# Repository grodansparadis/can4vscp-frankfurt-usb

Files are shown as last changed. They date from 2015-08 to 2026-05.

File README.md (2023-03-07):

<h1>Frankfurt USB</h1>



Buffered and isolated interface for CAN4VSCP

Frankurt USB is a high speed USB interface to the CAN4VSCP bus. It is not available inte 
<a href="http://www.frogshop.se">FrogShop</a> at the moment but will probaly be available this year.

It is planed in two versions. One for DIN montage/wall mountage as the rest of the CAN4VSCP modules and
one version that is boxed.
<hr>

This project is part of the <a href="http://www.vscp.org">VSCP (Very Simple Control Protocol) project</a>. 

<hr>

This project is licensed under the 
<a href="http://creativecommons.org/licenses/by-nc-sa/3.0/">Creative Commons open source license Attribution-NonCommercial-ShareAlike 3.0 Unported</a>. 
Other license options are available by conacting <a href="malto:info@grodansparadis.com">Paradis of the Frog AB</a>

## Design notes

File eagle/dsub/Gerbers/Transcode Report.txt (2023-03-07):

   ---- Transcoding 'C:\Users\grodansparadis\development\can4vscp_frankfurt_usb\eagle\dsub\Gerbers\pactec_version_rev_C.milling' ----   Mon Nov 02 14:24:04 2015

D10   --> D100
-----------------------------------------------------------------

   ---- Transcoding 'C:\Users\grodansparadis\development\can4vscp_frankfurt_usb\eagle\dsub\Gerbers\pactec_version_rev_C.plc' ----   Mon Nov 02 14:24:04 2015

D10   --> D103
D11   --> D104
D12   --> D105
D13   --> D106
D14   --> D107
D15   --> D108
D16   --> D109
D17   --> D110
D18   --> D111
D19   --> D112
D20   --> D113
D21   --> D114
D22   --> D115
D23   --> D116
D24   --> D117
D25   --> D118
D26   --> D119
D27   --> D120
D28   --> D121
D29   --> D122
D30   --> D123
D31   --> D124
D32   --> D125
D100  --> D126
-----------------------------------------------------------------

   ---- Transcoding 'C:\Users\grodansparadis\development\can4vscp_frankfurt_usb\eagle\dsub\Gerbers\pactec_version_rev_C.pls' ----   Mon Nov 02 14:24:04 2015

D10   --> D127
D11   --> D128
-----------------------------------------------------------------

   ---- Transcoding 'C:\Users\grodansparadis\development\can4vscp_frankfurt_usb\eagle\dsub\Gerbers\pactec_version_rev_C.pmc' ----   Mon Nov 02 14:24:04 2015

D10   --> D129
D11   --> D130
D12   --> D131
D13   --> D132
D14   --> D133
D15   --> D134
D16   --> D135
D17   --> D136
D18   --> D137
D19   --> D138
D20   --> D139
D21   --> D140
-----------------------------------------------------------------

   ---- Transcoding 'C:\Users\grodansparadis\development\can4vscp_frankfurt_usb\eagle\dsub\Gerbers\pactec_version_rev_C.pms' ----   Mon Nov 02 14:24:04 2015

D10   --> D141
-----------------------------------------------------------------

   ---- Transcoding 'C:\Users\grodansparadis\development\can4vscp_frankfurt_usb\eagle\dsub\Gerbers\pactec_version_rev_C.sol' ----   Mon Nov 02 14:24:04 2015

D13   --> D142
D14   --> D143
D15   --> D144
D16   --> D145
D17   --> D146
D18   --> D147
D19   --> D148
D20   --> D149
D21   --> D150
-----------------------------------------------------------------

   ---- Transcoding 'C:\Users\grodansparadis\development\can4vscp_frankfurt_usb\eagle\dsub\Gerbers\pactec_version_rev_C.stc' ----   Mon Nov 02 14:24:04 2015

D10   --> D151
D11   --> D152
D12   --> D153
D13   --> D154
D14   --> D155
D15   --> D156
D16   --> D157
D17   --> D158
D18   --> D159
D19   --> D160
D20   --> D161
D21   --> D162
D22   --> D163
D23   --> D164
D24   --> D165
D25   --> D166
D26   --> D167
D27   --> D168
D28   --> D169
-----------------------------------------------------------------

   ---- Transcoding 'C:\Users\grodansparadis\development\can4vscp_frankfurt_usb\eagle\dsub\Gerbers\pactec_version_rev_C.sts' ----   Mon Nov 02 14:24:04 2015

D10   --> D170
D11   --> D171
D12   --> D172
D13   --> D173
D14   --> D174
D15   --> D175
D16   --> D176
D17   --> D177
-----------------------------------------------------------------

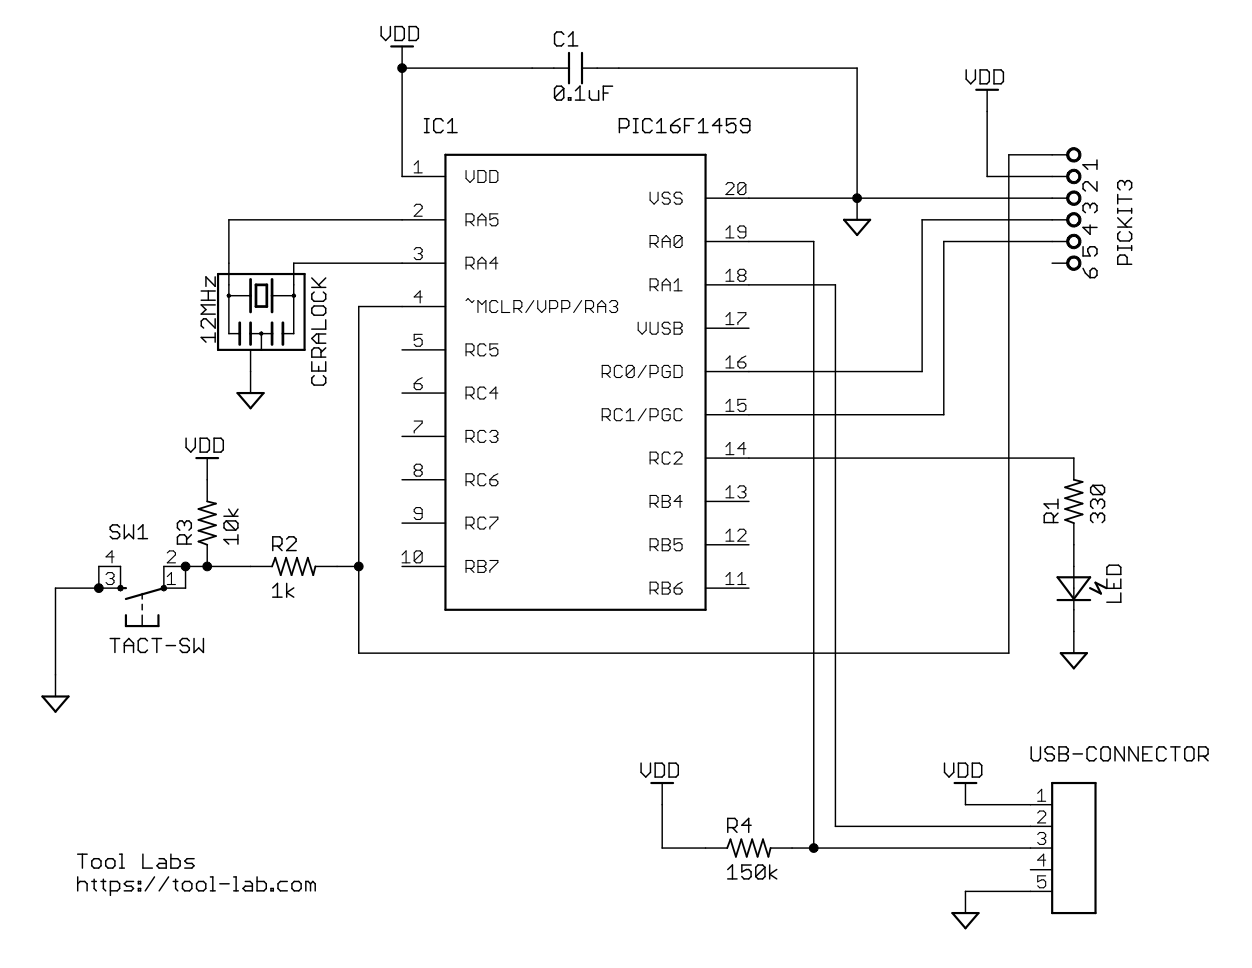
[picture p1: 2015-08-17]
docs/schematics-16F1459.png

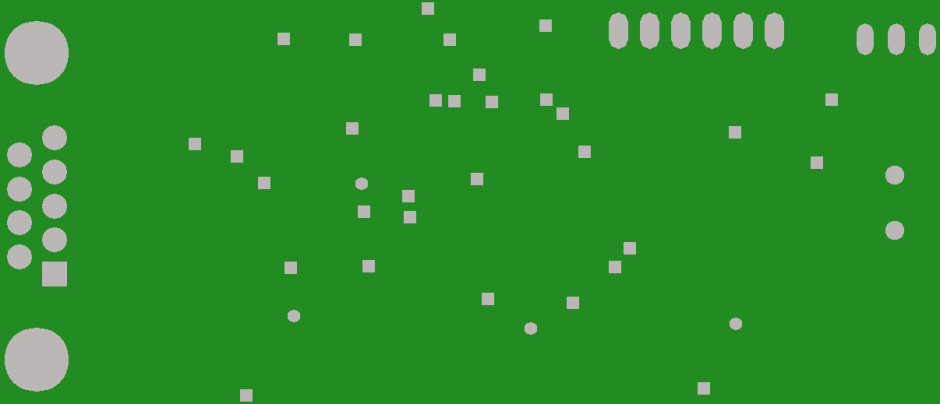
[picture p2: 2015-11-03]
eagle/dsub/Gerbers/frankfurt_usb_pac_rev_c_gbs_small.png

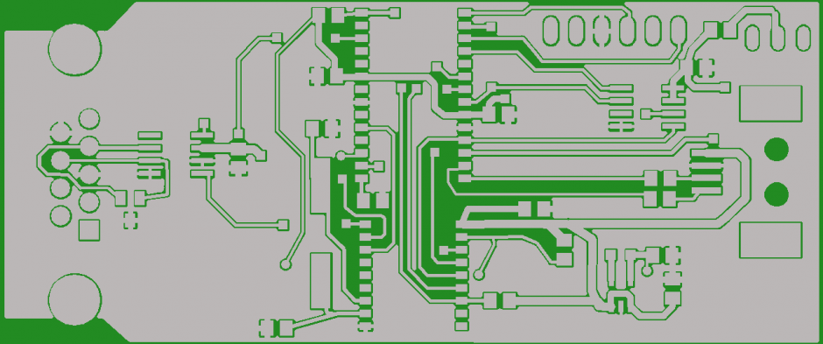
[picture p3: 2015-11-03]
eagle/dsub/Gerbers/frankfurt_usb_pac_rev_c_gtl_small.png

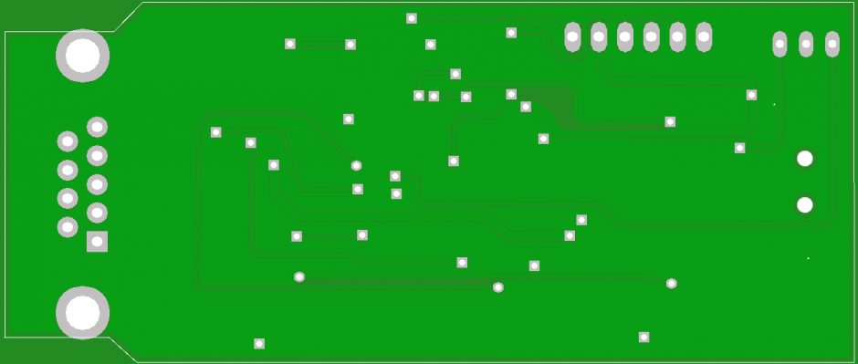
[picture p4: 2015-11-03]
eagle/dsub/Gerbers/frankfurt_usb_pac_rev_c_bottom_small.png

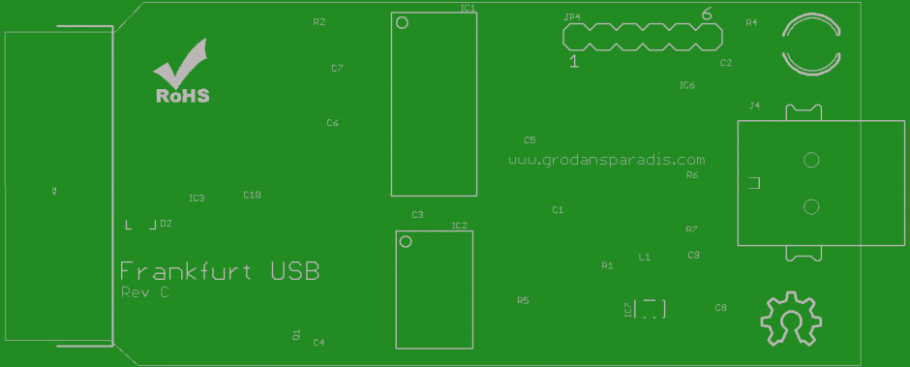
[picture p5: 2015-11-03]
eagle/dsub/Gerbers/frankfurt_usb_pac_rev_c_gto_small.png

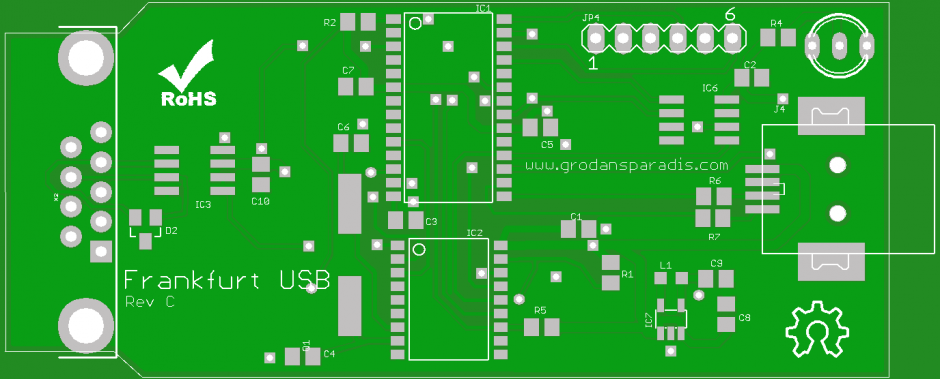
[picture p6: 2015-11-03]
eagle/dsub/Gerbers/frankfurt_usb_pac_rev_c_top_small.png

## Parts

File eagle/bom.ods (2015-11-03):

Partl | ist exported from | C:/Users/akhe/Doc | uments/develo | pment/hardware_zeus/can4vscp/can4vscp_usb/eagle/smd_can | 4vscp_usb_0.0.2.sch at 2 | 011-10-03 | 11:29:21
Part | Value | Device | Package | Description | Description | Supplier | Partnumber | Price
C1 | 100nF | C-EUC0805 | C0805 | CAPACITOR, European symbol | Avkopplingskondensator | Bejoken | 522526 | 0,07
C2 | 0.1uF | C-EUC0805 | C0805 | CAPACITOR, European symbol | Avstörningskondensator | Bejoken | 522526 | 0,07
C4 | 15pF | C-EUC0805 | C0805 | CAPACITOR, European symbol | Kondensator | Bejoken | 522419 | 0,11
C5 | 0.1uF | C-EUC0805 | C0805 | CAPACITOR, European symbol | Avstörningskondensator | Bejoken | 522526 | 0,07
C6 | 15pF | C-EUC0805 | C0805 | CAPACITOR, European symbol | Kondensator | Bejoken | 522419 | 0,11
D2 | NUP2105L | DIODE-2CA|ACSOT23 | SOT23 | Dual DIODE Cathode-Anode|Anode-Cathode | Tansient protection | Digikey | NUP2105LT1GOSCT-ND | 4
IC1 | PIC18LF2550-I/SO | PIC18LF2550-I/SO | SO-28W | PIC18*2550 Microchip FLASH Microcontroller with FS-USB | USB Microcontrole | Digikey | PIC18F2550-I/SO-ND | 50,4
IC2 | MCP2515 | MCP2515 | SO-18W |  | CAN Controller | Digikey | MCP2515-I/SO-ND | 15,84
IC3 | MCP2551SN | MCP2551SN | SO-08 | High Speed CAN tranceiver | CAN tranceiver | Digikey | MCP2551-I/SN-ND | 8,96
IC4 | ISO1050 | ISO1050 | DUB_PSOP |  | Isolated CAN tranceiver | Digikey | 296-24818-1-ND | 37,2
IC5 | DCDC_MER1 | DCDC_MER1 | MER1 |  | DC DC converter | Digikey | 811-2124-5-ND | 63,6
IC6 | MCP23A256 | MCP23A256 | SO-8 |  | Serial RAM | Digikey | 23A256-I/SN-ND | 12,96
J2 | A00-108-220-450 | A00-108-220-450 | RJ-45 |  | RJ-45 connector | Digikey | 151-1099-nd | 5,6
J3 |  | MA03-1 | MA03-1 | PIN HEADER | Enkel stiftlist | Digikey | SAM1035-50-ND | 0,33
JP4 |  | MA06-1 | MA06-1 | PIN HEADER | Enkel stiftlist | Digikey | SAM1035-50-ND | 0,33
LED1 |  | LEDCHIP-LED0805 | CHIP-LED0805 | LED | Green LED | Digikey | 475-1410-1-nd | 0,88
LED2 |  | LEDCHIP-LED0805 | CHIP-LED0805 | LED | Green LED | Digikey | 475-1410-1-nd | 0,88
Q1 | 12 MHZ | HC-49S | 9C | Digikey 887-1050-1-nd | Crystal | Digikey | 887-1053-1-ND | 2,56
R1 | 10K | R-EU_R0805 | R0805 | RESISTOR, European symbol | Resistor | Bejoken | 454676 | 0,01
R2 | 10K | R-EU_R0805 | R0805 | RESISTOR, European symbol | Resistor | Bejoken | 454676 | 0,01
R3 | 1K | R-EU_R0805 | R0805 | RESISTOR, European symbol | Resistor | Bejoken | 454650 | 0,01
R4 | 1K | R-EU_R0805 | R0805 | RESISTOR, European symbol | Resistor | Bejoken | 454650 | 0,01
R5 | 10K | R-EU_R0805 | R0805 | RESISTOR, European symbol | Resistor | Bejoken | 454676 | 0,01
X1 | USB-B-S | USB-B-S | USB-B-SMT | USB Connectors | USB B connector | Digikey | ED2994-ND | 8,8
 |  |  |  |  |  |  |  | 212,82

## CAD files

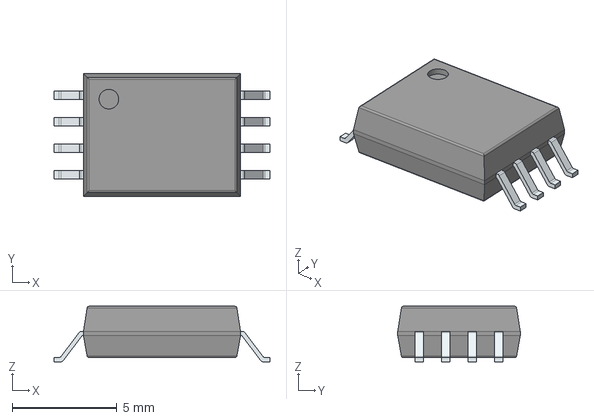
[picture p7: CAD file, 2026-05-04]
kicad/lbr/ADM3050EBRIZ-RL/3D/ADM3050EBRIZ-RL.stp
10.3 x 5.85 x 2.65 mm
PinsArrayLR

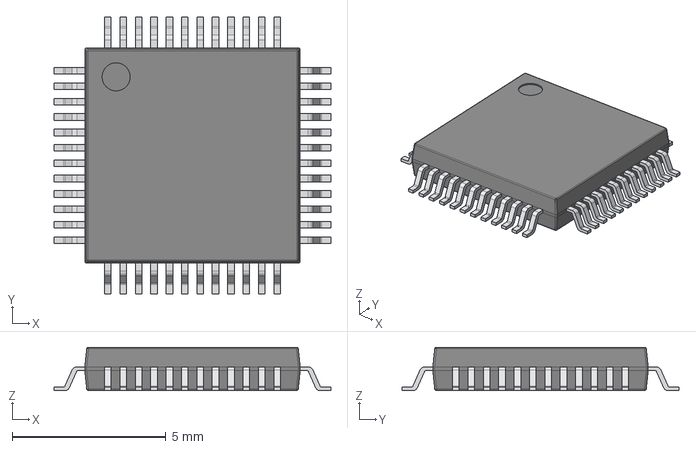
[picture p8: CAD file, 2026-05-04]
kicad/lbr/LIB_STM32C552CET6/STM32C552CET6/3D/STM32C552CET6.stp
9.00 x 9.00 x 1.41 mm

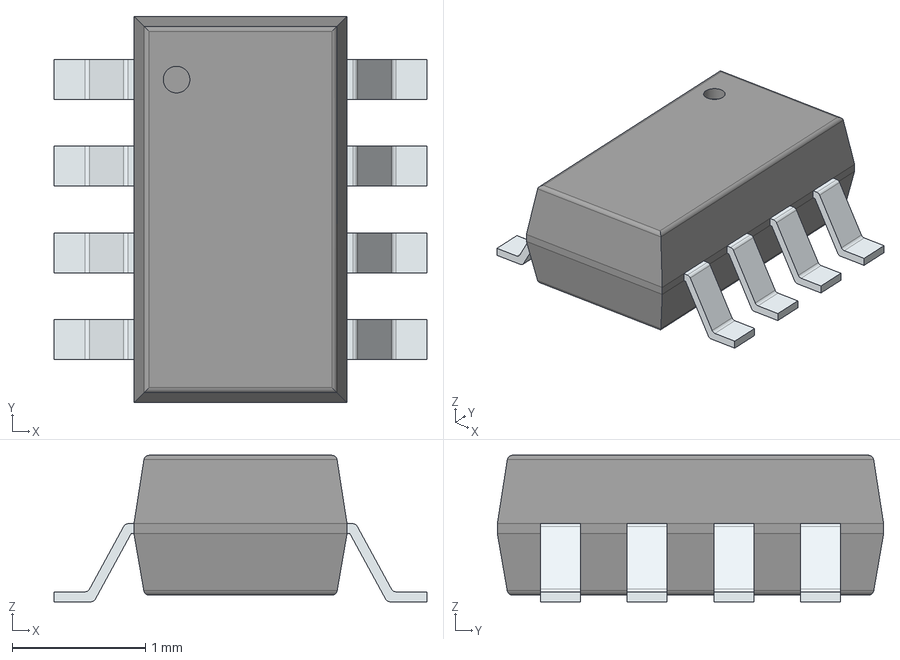
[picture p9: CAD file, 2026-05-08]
kicad/lbr/LIB_TCAN3403DDFRQ1/TCAN3403DDFRQ1/3D/TCAN3403DDFRQ1.stp
2.80 x 2.90 x 1.10 mm
PinsArrayLR

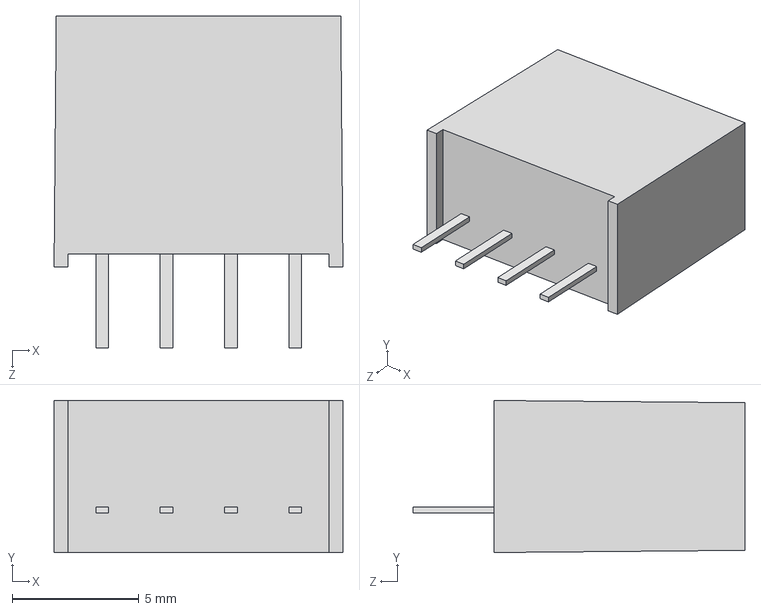
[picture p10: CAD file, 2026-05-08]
kicad/lbr/TME_0505S/tme_3d_drawing.stp
11.4 x 6.00 x 13.1 mm
TME Series
TME PIN x 4

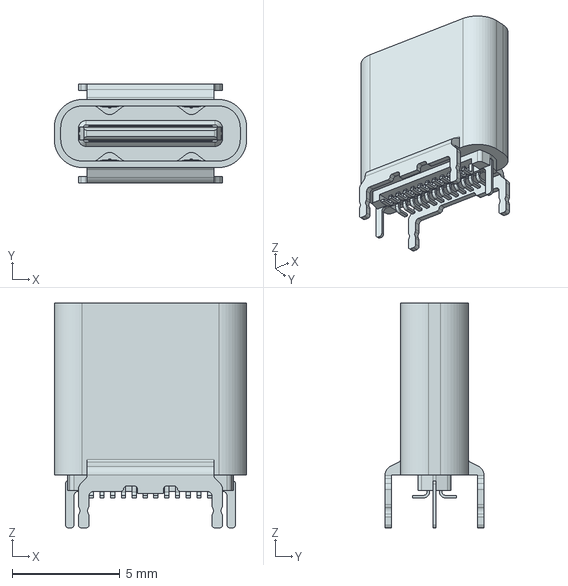
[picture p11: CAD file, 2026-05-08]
kicad/lbr/2047110001/2047110001.stp
8.94 x 4.60 x 10.4 mm

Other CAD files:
kicad/lbr/ADM3050EBRIZ-RL/Allegro/soic127p1031x265-8n.psm
kicad/lbr/ADM3050EBRIZ-RL/DEHDL/adm3050ebriz_rl/chips/chips.prt
kicad/lbr/LIB_STM32C552CET6/STM32C552CET6/Allegro/qfp50p900x900x160-48n.psm
kicad/lbr/LIB_STM32C552CET6/STM32C552CET6/DEHDL/stm32c552cet6/chips/chips.prt
kicad/lbr/LIB_TCAN3403DDFRQ1/TCAN3403DDFRQ1/Allegro/sot65p280x110-8n.psm
kicad/lbr/LIB_TCAN3403DDFRQ1/TCAN3403DDFRQ1/DEHDL/tcan3403ddfrq1/chips/chips.prt

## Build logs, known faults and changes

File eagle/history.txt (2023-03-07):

CAN4VSCP - USB
==============

2015-12-03 AKHE - Processor is PIC18F25K50
2015-11-01 AKHE - Changed processor to PIC18F26J50. 3.3V design.
2015-05-08 AKHE - Fixed lengths on tracks and added CAP on VUSB.
2015-05-08 AKHE - Added J5 pin power connector.
2011-12-20 AKHE - Added termination resistor. Leave unpopulated.
2011-11-10 AKHE - GND Switch fixed. GND is at 6,7,8
2011-11-10 AKHE - CANH should be on pin 4 of RJ-45
2011-11-10 AKHE - Rev B

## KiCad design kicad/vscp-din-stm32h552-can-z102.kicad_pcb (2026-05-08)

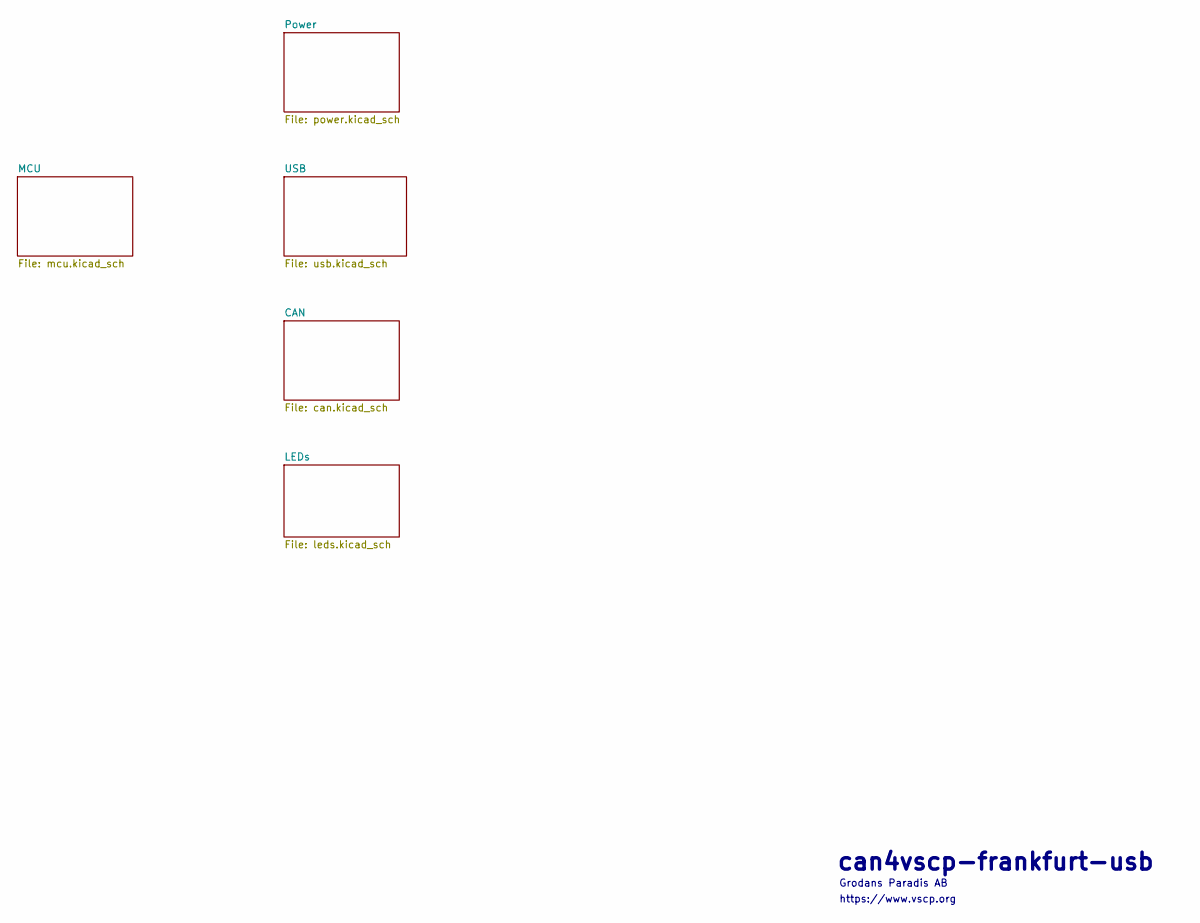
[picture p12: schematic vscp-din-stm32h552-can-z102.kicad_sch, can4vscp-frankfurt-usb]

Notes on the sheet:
https://www.vscp.org
can4vscp-frankfurt-usb
Grodans Paradis AB

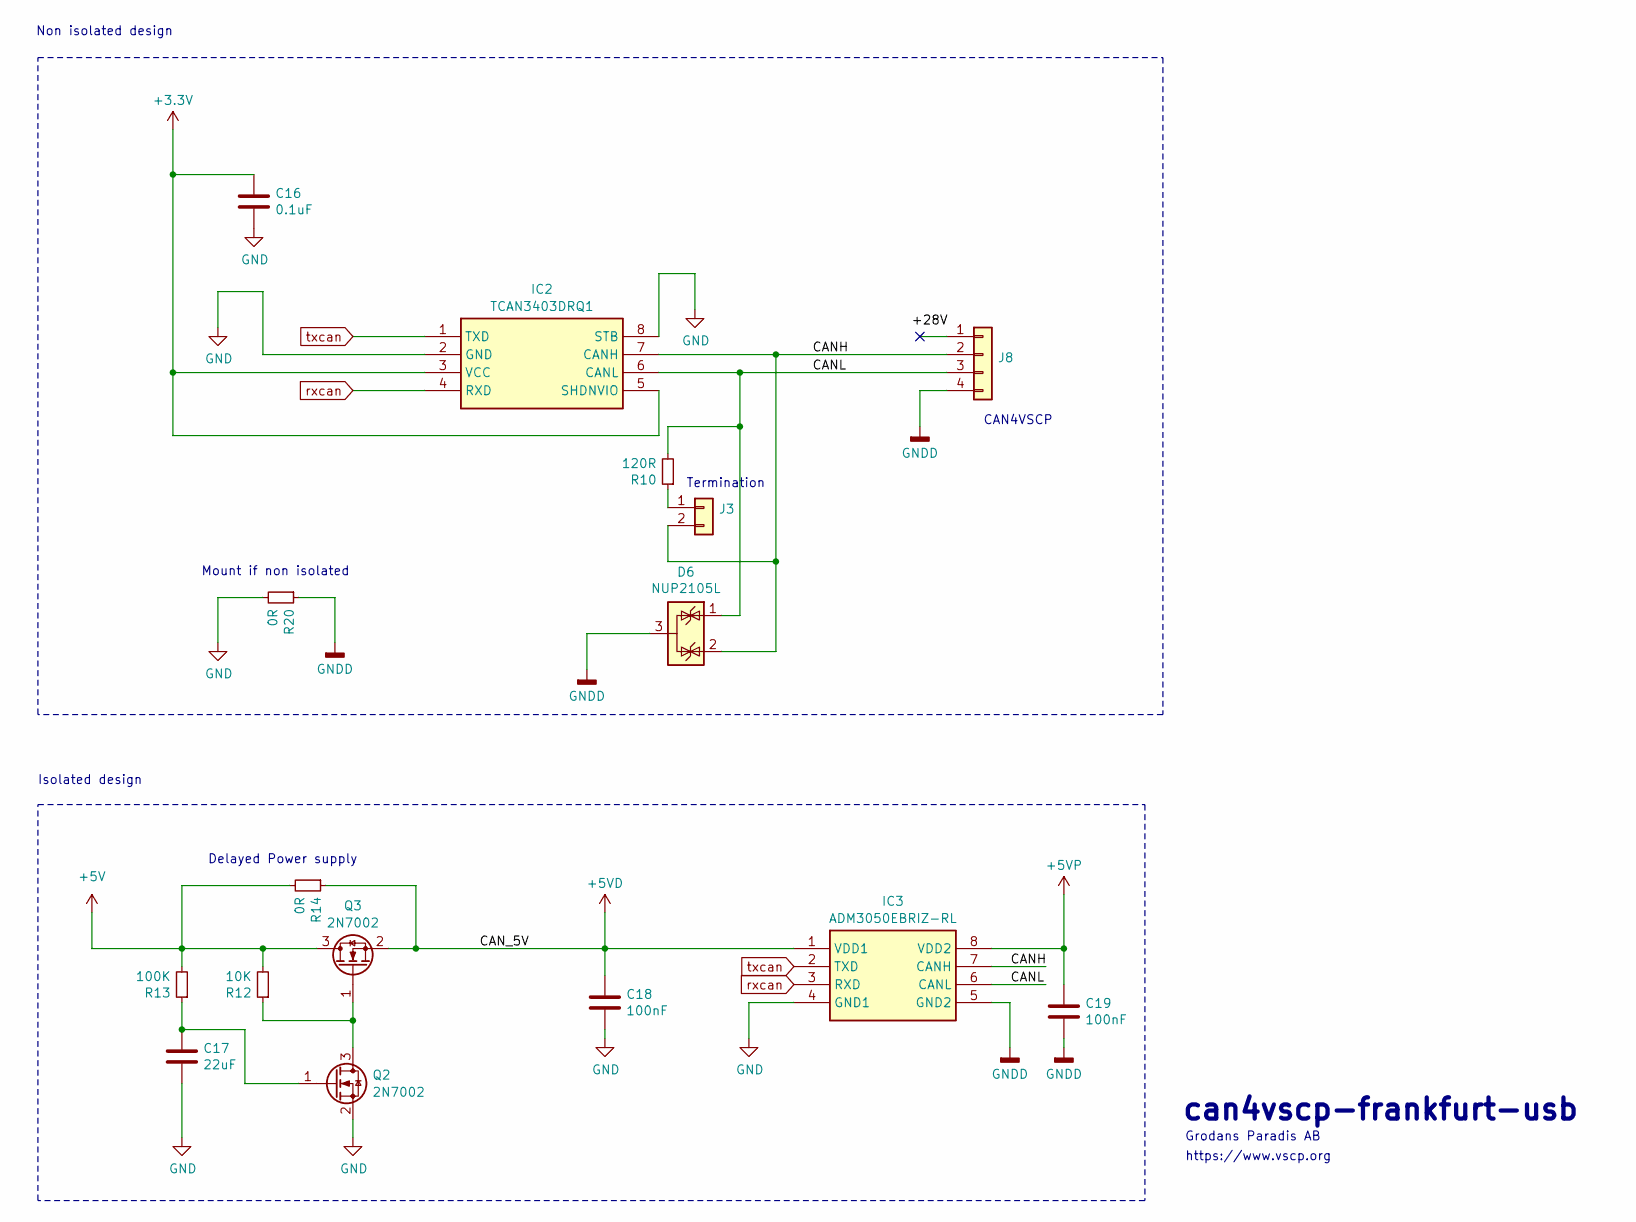
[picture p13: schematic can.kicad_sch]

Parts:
C16: 0.1uF; C_0805_2012Metric_Pad1.18x1.45mm_HandSolder
C17: 22uF; C_0805_2012Metric_Pad1.18x1.45mm_HandSolder
C18, C19: 100nF; C_0805_2012Metric_Pad1.18x1.45mm_HandSolder
D6: NUP2105L; SOT-23
IC2: TCAN3403DRQ1; SOIC127P600X175-8N; Mouser Part Number 595-TCAN3403DRQ1
IC3: ADM3050EBRIZ-RL; SOIC127P1031X265-8N; Mouser Part Number 584-ADM3050EBRIZ-RL
J3: Conn_01x02; PinHeader_1x02_P2.54mm_Vertical
J8: Conn_01x04; PhoenixContact_MC_1,5_4-G-3.81_1x04_P3.81mm_Horizontal
Q2, Q3: 2N7002; SOT-23
R10: 120R; R_0805_2012Metric_Pad1.20x1.40mm_HandSolder
R12: 10K; R_0805_2012Metric_Pad1.20x1.40mm_HandSolder
R13: 100K; R_0805_2012Metric_Pad1.20x1.40mm_HandSolder
R14, R20: 0R; R_0805_2012Metric_Pad1.20x1.40mm_HandSolder

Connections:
+3.3V: C16.1, IC2.3 (VCC), IC2.5 (SHDNVIO); also elsewhere on the board
+5V: Q3.3 (D), R12.2, R13.2, R14.2; also elsewhere on the board
+5VD: C18.1, IC3.1 (VDD1), Q3.2 (S), R14.1
+5VP: C19.1, IC3.8 (VDD2); also elsewhere on the board
/CAN/CANH: D6.2 (K), IC2.7 (CANH), IC3.7 (CANH), J3.2, J8.2
/CAN/CANL: D6.1 (K), IC2.6 (CANL), IC3.6 (CANL), J8.3, R10.2
GND: C16.2, C17.2, C18.2, IC2.2 (GND), IC2.8 (STB), IC3.4 (GND1), Q2.2 (S), R20.2; also elsewhere on the board
GNDD: C19.2, D6.3 (A), IC3.5 (GND2), J8.4, R20.1; also elsewhere on the board
unnamed: J3.1, R10.1
unnamed: Q2.3 (D), Q3.1 (G), R12.1
unnamed: C17.1, Q2.1 (G), R13.1
rxcan: IC2.4 (RXD), IC3.3 (RXD); also elsewhere on the board
txcan: IC2.1 (TXD), IC3.2 (TXD); also elsewhere on the board

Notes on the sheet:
Termination
CAN4VSCP
https://www.vscp.org
Delayed Power supply
Isolated design
Non isolated design
can4vscp-frankfurt-usb
Grodans Paradis AB
Mount if non isolated

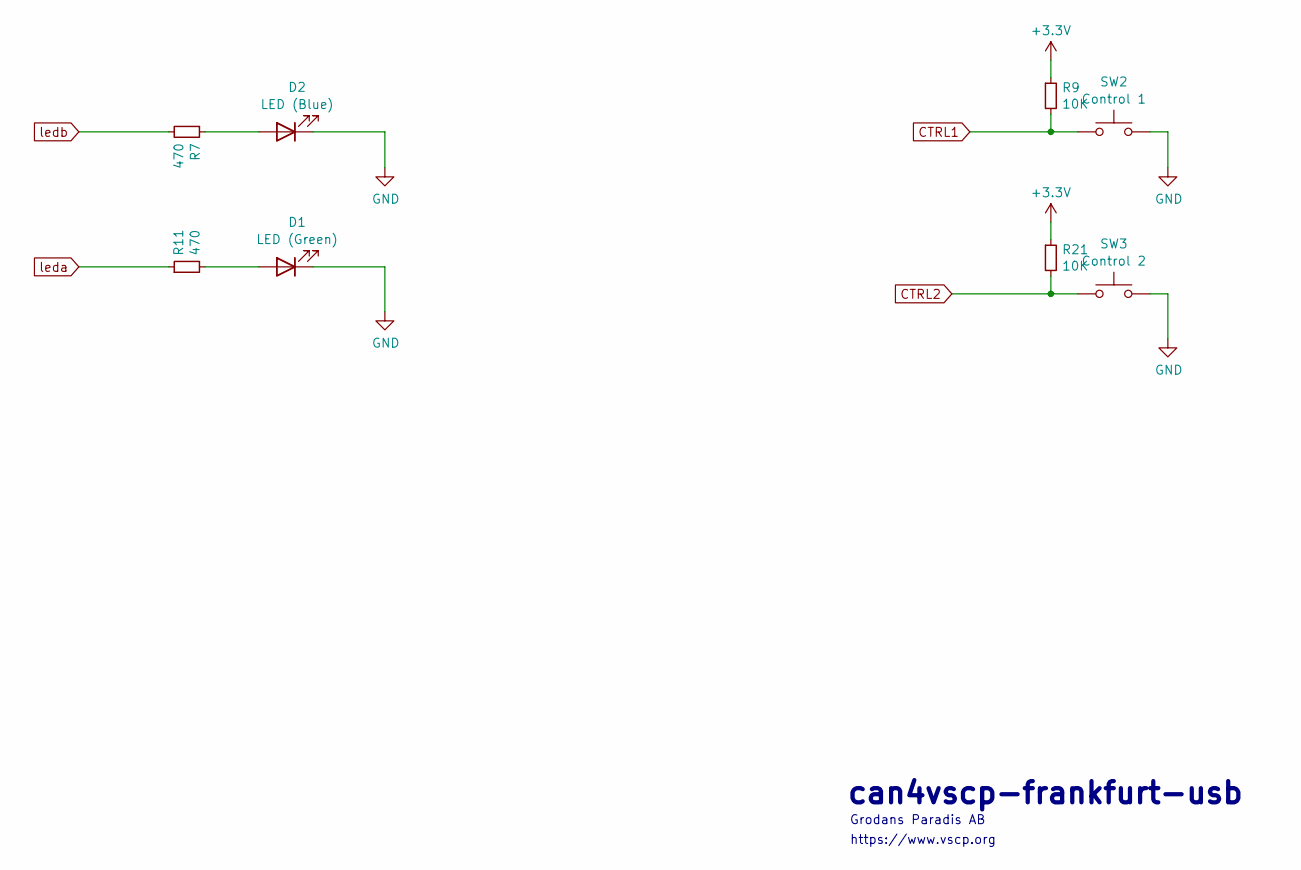
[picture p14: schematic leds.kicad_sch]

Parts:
D1: LED (Green); LED_0805_2012Metric
D2: LED (Blue); LED_0805_2012Metric
R7, R11: 470; R_0805_2012Metric
R9, R21: 10K; R_0805_2012Metric
SW2: Control 1; SW_SPST_Omron_B3FS-100xP
SW3: Control 2; SW_SPST_Omron_B3FS-100xP

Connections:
+3.3V: R9.1, R21.1; also elsewhere on the board
CTRL1: R9.2, SW2.1
CTRL2: R21.2, SW3.1
GND: D1.1 (K), D2.1 (K), SW2.2, SW3.2; also elsewhere on the board
unnamed: D1.2 (A), R11.2
unnamed: D2.2 (A), R7.1
leda: R11.1
ledb: R7.2

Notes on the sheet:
can4vscp-frankfurt-usb
https://www.vscp.org
Grodans Paradis AB

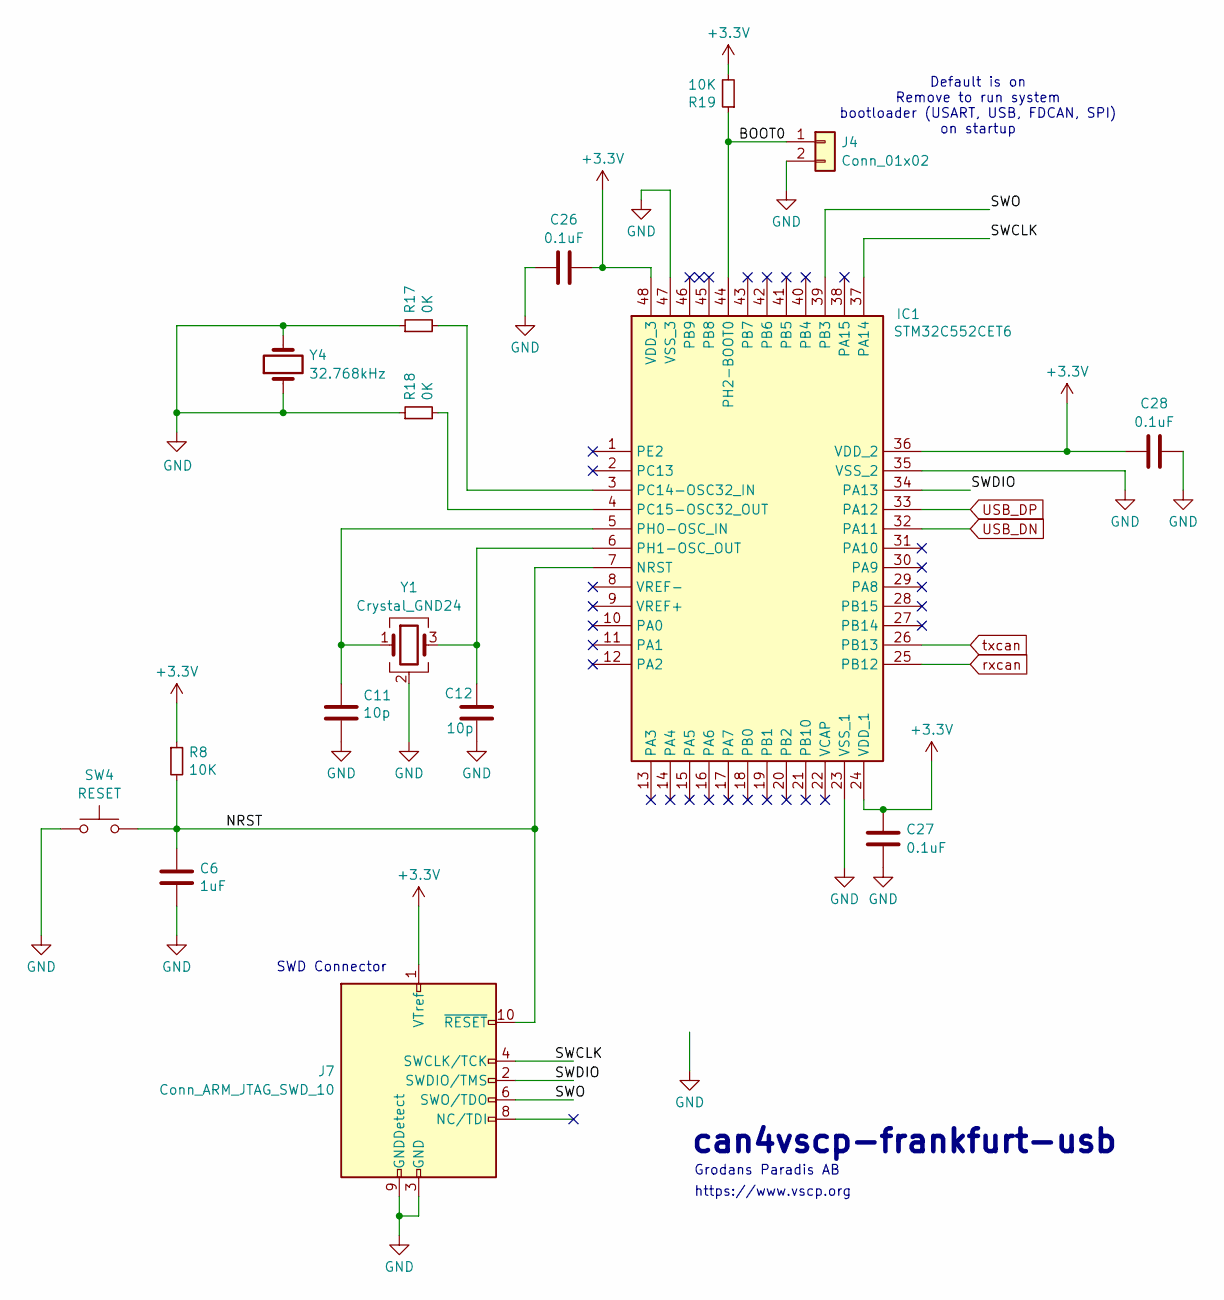
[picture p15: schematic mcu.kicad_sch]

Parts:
C6: 1uF; C_0805_2012Metric_Pad1.18x1.45mm_HandSolder
C11, C12: 10p; C_0805_2012Metric_Pad1.18x1.45mm_HandSolder
C26, C27, C28: 0.1uF; C_0805_2012Metric_Pad1.18x1.45mm_HandSolder
IC1: STM32C552CET6; QFP50P900X900X160-48N; Manufacturer_Part_Number STM32C552CET6
J4: Conn_01x02; PinHeader_1x02_P2.54mm_Vertical
J7: Conn_ARM_JTAG_SWD_10; PinHeader_2x05_P1.27mm_Vertical
R8: 10K; R_0805_2012Metric
R17, R18: 0K; R_0805_2012Metric_Pad1.20x1.40mm_HandSolder
R19: 10K; R_0805_2012Metric_Pad1.20x1.40mm_HandSolder
SW4: RESET; SW_SPST_Omron_B3FS-100xP
Y1: Crystal_GND24; Crystal_SMD_TXC_7M-4Pin_3.2x2.5mm_HandSoldering
Y4: 32.768kHz; Resonator-2Pin_W6.0mm_H3.0mm

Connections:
+3.3V: C26.2, C27.2, C28.1, IC1.24 (VDD_1), IC1.36 (VDD_2), IC1.48 (VDD_3), J7.1 (VTref), R8.1, R19.2; also elsewhere on the board
/MCU/BOOT0: IC1.44 (PH2-BOOT0), J4.1, R19.1
/MCU/NRST: C6.1, IC1.7 (NRST), J7.10 (~RESET), R8.2, SW4.2
/MCU/SWCLK: IC1.37 (PA14), J7.4 (SWCLK/TCK)
/MCU/SWDIO: IC1.34 (PA13), J7.2 (SWDIO/TMS)
/MCU/SWO: IC1.39 (PB3), J7.6 (SWO/TDO)
GND: C6.2, C11.2, C12.2, C26.1, C27.1, C28.2, IC1.23 (VSS_1), IC1.35 (VSS_2), IC1.47 (VSS_3), J4.2, J7.3 (GND), J7.5 (GND), J7.9 (GNDDetect), R17.1, R18.1, SW4.1, Y1.2 (G), Y1.4 (G), Y4.1, Y4.2; also elsewhere on the board
unnamed: IC1.3 (PC14-OSC32_IN), R17.2
unnamed: IC1.4 (PC15-OSC32_OUT), R18.2
unnamed: C11.1, IC1.5 (PH0-OSC_IN), Y1.1
unnamed: C12.1, IC1.6 (PH1-OSC_OUT), Y1.3
USB_DN: IC1.32 (PA11); also elsewhere on the board
USB_DP: IC1.33 (PA12); also elsewhere on the board
rxcan: IC1.25 (PB12); also elsewhere on the board
txcan: IC1.26 (PB13); also elsewhere on the board

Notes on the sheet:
https://www.vscp.org
SWD Connector
Default is on Remove to run system bootloader (USART, USB, FDCAN, SPI) on startup
Grodans Paradis AB
can4vscp-frankfurt-usb

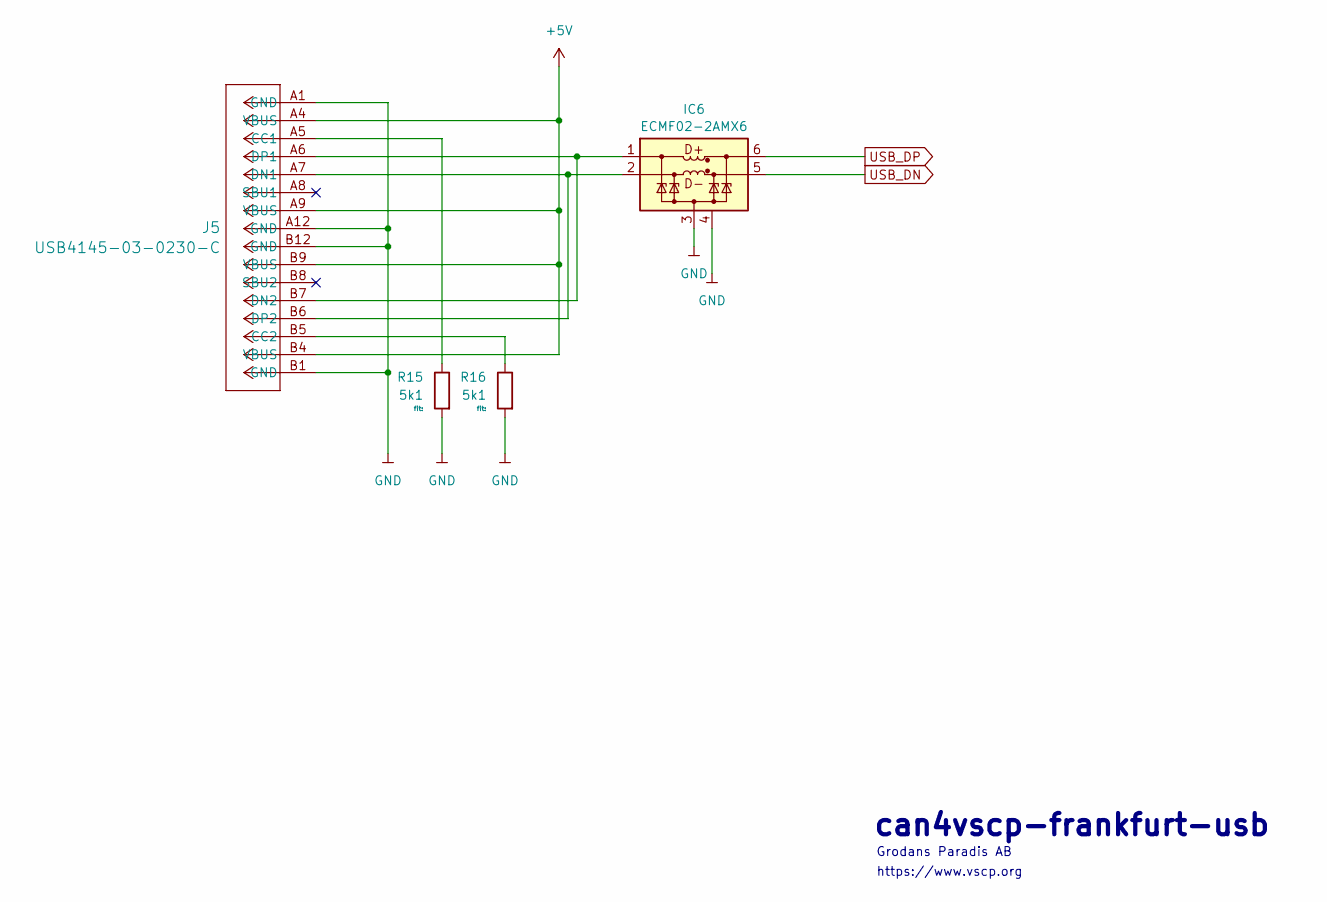
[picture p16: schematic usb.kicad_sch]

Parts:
IC6: ECMF02-2AMX6; ST_UQFN-6L_1.5x1.7mm_P0.5mm
J5: USB4145-03-0230-C; CONN_USB4145-03-0230-C_GCT
R15, R16: 5k1_0603_100mW_1%_E24_Chip-Resistor; R_0805_2012Metric; MPN any

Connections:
+5V: J5.A4 (VBUS), J5.A9 (VBUS), J5.B4 (VBUS), J5.B9 (VBUS); also elsewhere on the board
GND: IC6.3 (GND), IC6.4 (NC), J5.A1 (GND), J5.A12 (GND), J5.B1 (GND), J5.B12 (GND), R15.2, R16.2; also elsewhere on the board
unnamed: IC6.1 (D+_in), J5.A6 (DP1), J5.B7 (DN2)
unnamed: IC6.2 (D-_in), J5.A7 (DN1), J5.B6 (DP2)
unnamed: J5.A5 (CC1), R15.1
unnamed: J5.B5 (CC2), R16.1
USB_DN: IC6.5 (D-_out); also elsewhere on the board
USB_DP: IC6.6 (D+_out); also elsewhere on the board

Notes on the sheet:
https://www.vscp.org
Grodans Paradis AB
can4vscp-frankfurt-usb

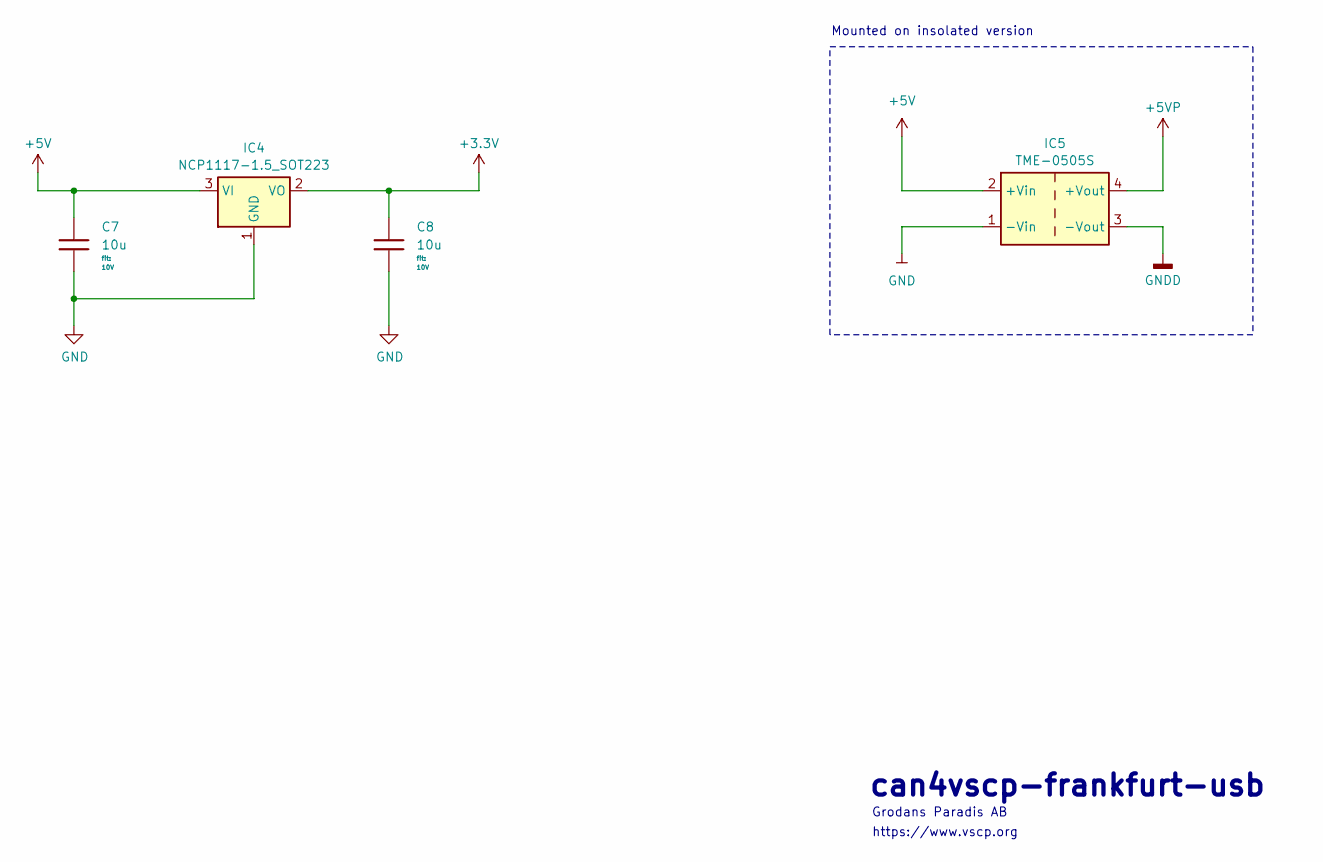
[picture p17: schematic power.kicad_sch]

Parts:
C7, C8: 10u_0805_X7R_10%_10V_-40C..125C_Chip-Capacitor; C_0805_2012Metric; MPN any
IC4: NCP1117-1.5_SOT223; SOT-223-3_TabPin2
IC5: TME-0505S; Converter_DCDC_TRACO_TME_03xxS_05xxS_12xxS_Single_THT

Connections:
+3.3V: C8.1, IC4.2 (VO); also elsewhere on the board
+5V: C7.1, IC4.3 (VI), IC5.2 (+Vin); also elsewhere on the board
+5VP: IC5.4 (+Vout); also elsewhere on the board
GND: C7.2, C8.2, IC4.1 (GND), IC5.1 (-Vin); also elsewhere on the board
GNDD: IC5.3 (-Vout); also elsewhere on the board

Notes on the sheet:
can4vscp-frankfurt-usb
Mounted on insolated version
https://www.vscp.org
Grodans Paradis AB

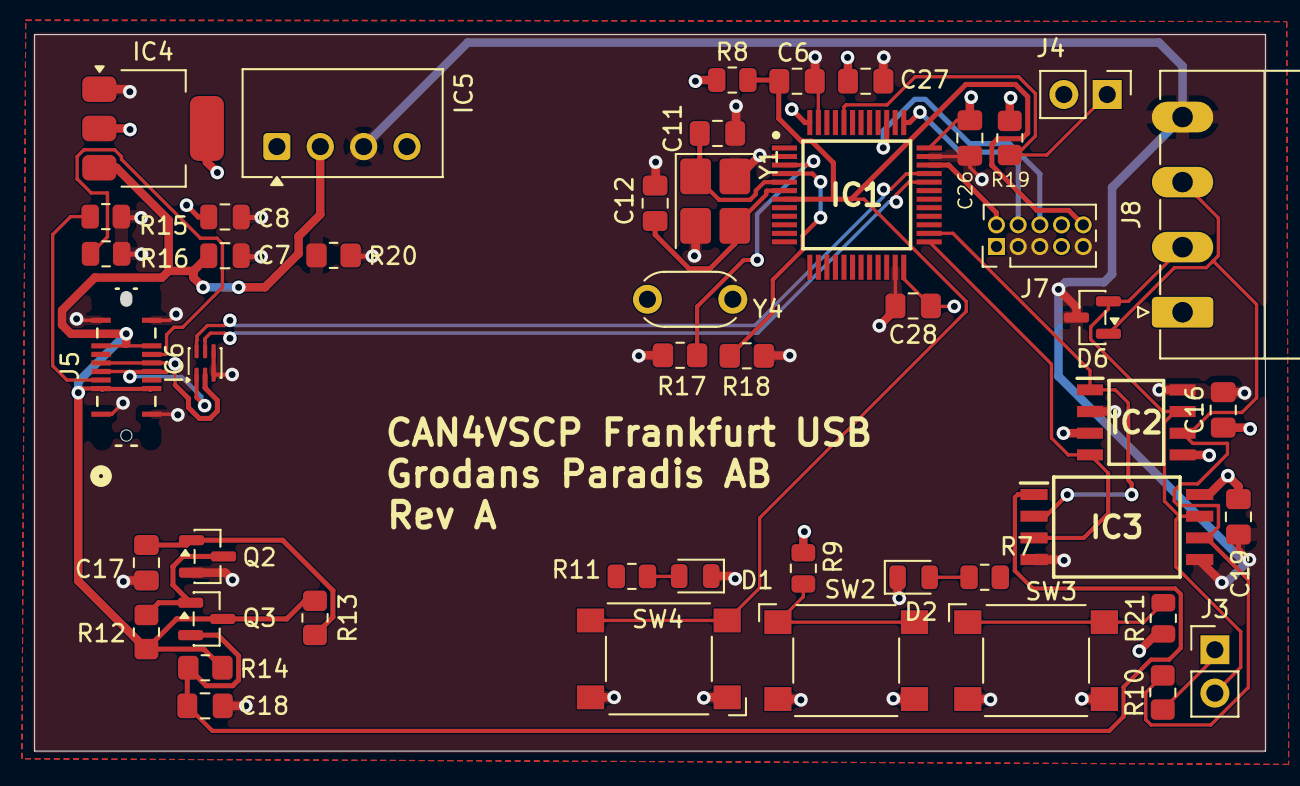
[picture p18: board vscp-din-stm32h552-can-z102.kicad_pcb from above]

Board: 4 copper layers, 72.1 x 42.0 mm, 48 parts (0 on the bottom side), 32 nets.

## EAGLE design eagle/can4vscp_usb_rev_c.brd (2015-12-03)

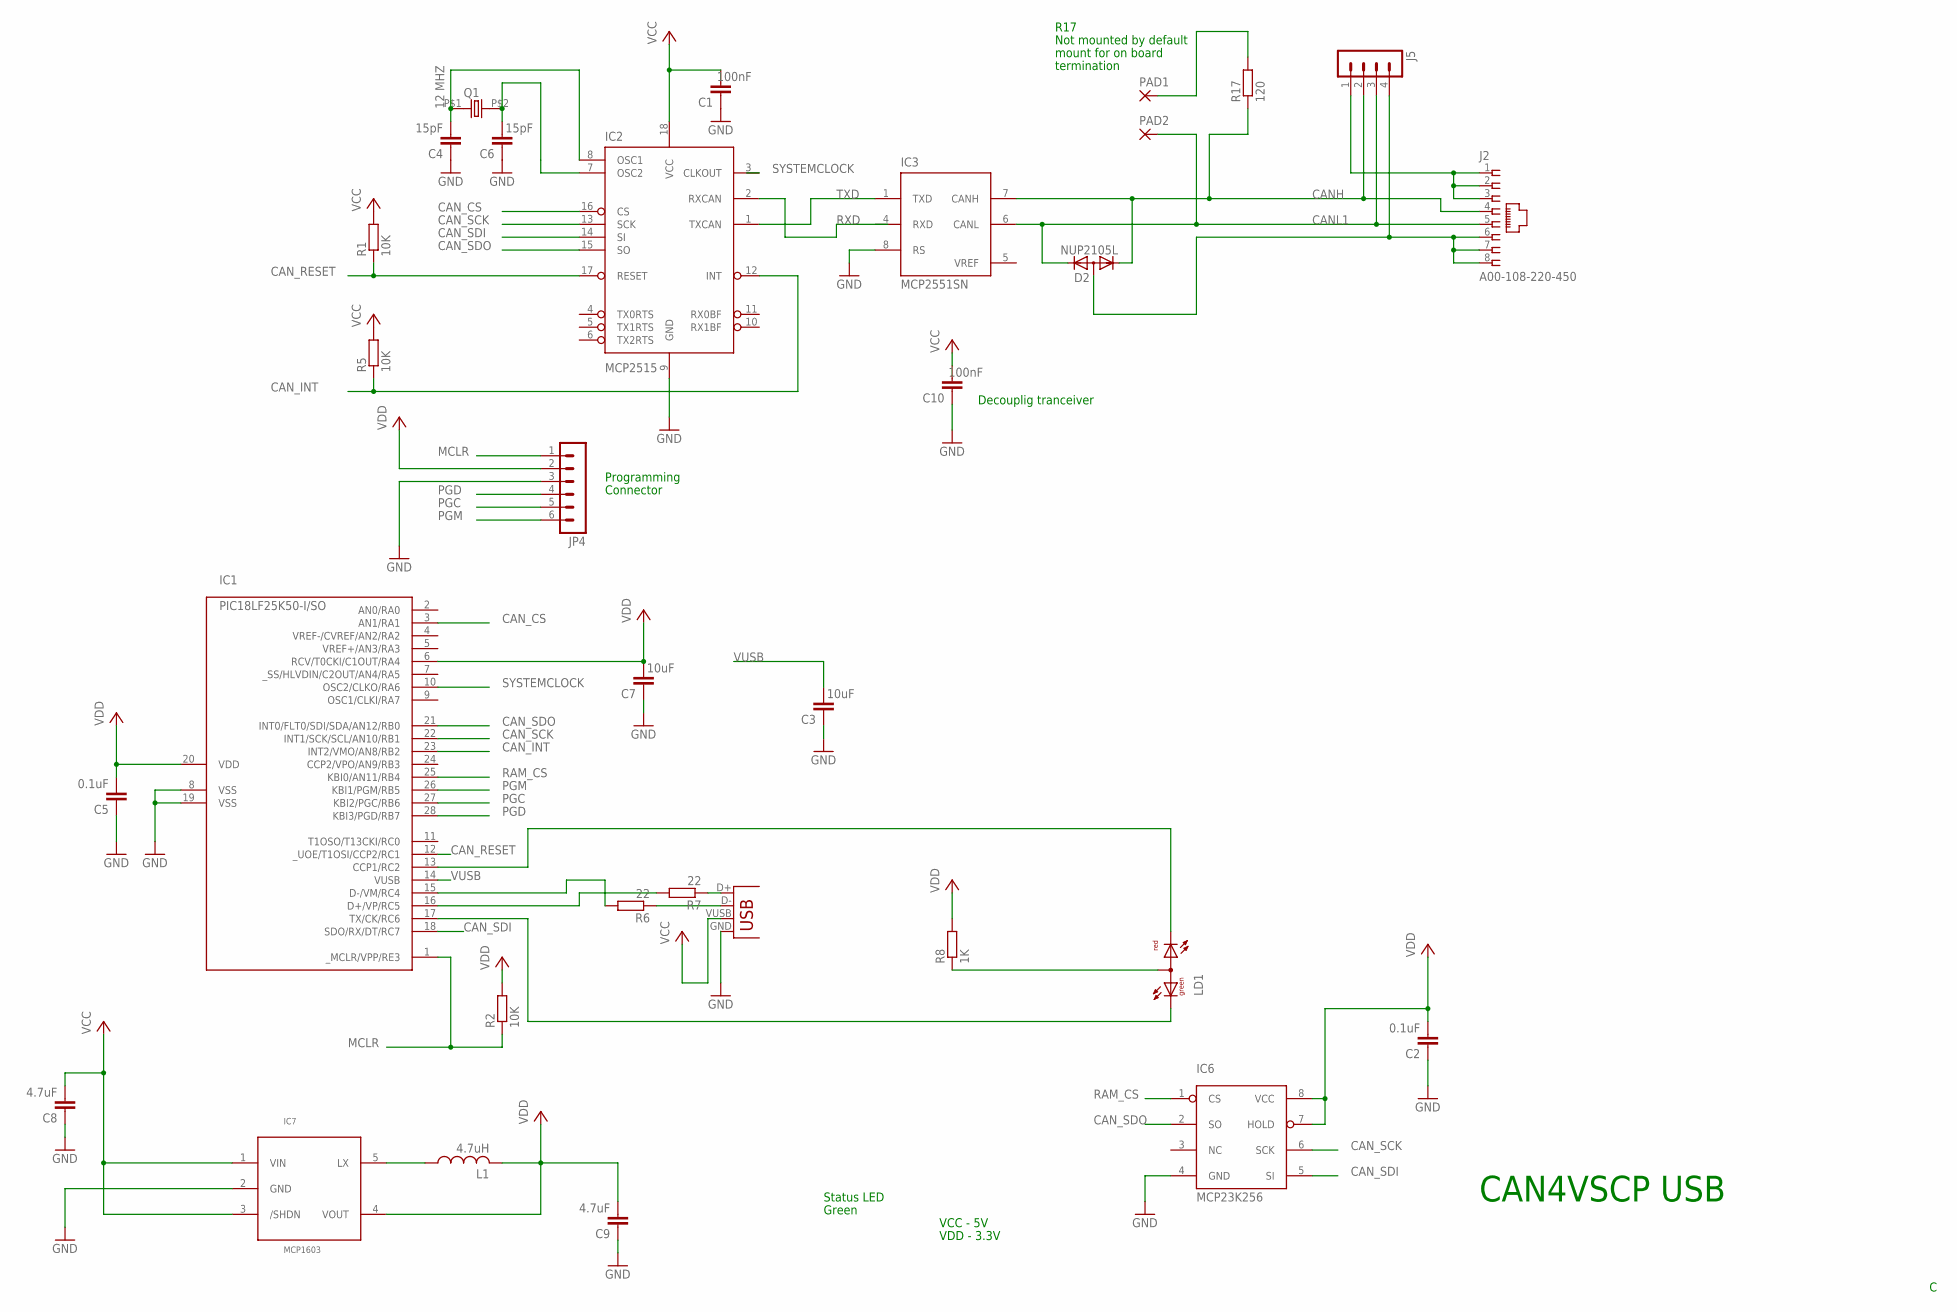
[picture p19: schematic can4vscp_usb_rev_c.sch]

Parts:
C1, C10: 100nF; C0805
C2, C5: 0.1uF; C0805
C3, C7: 10uF; C0805
C4, C6: 15pF; C0805
C8, C9: 4.7uF; C0805
D2: NUP2105L; SOT23
IC1: PIC18LF25K50-I/SO; SO-28W
IC2: MCP2515; SO-18W
IC3: MCP2551SN; SO-08
IC6: MCP23K256; SO-8
IC7: MCP1603; SOT23-5L
J2: A00-108-220-450; RJ-45
J4: USB-B-S; USB-B-SMT
J5: MA04-1
JP4: MA06-1
L1: 4.7uH; L2012C
LD1: DUOLED-RG-A; DUOLED-A-5MM
PAD1, PAD2: 1,6/0,8
Q1: 12 MHZ; 9C
R1, R2, R5: 10K; R0805
R6, R7: 22; R0805
R8: 1K; R0805
R17: 120; R0805

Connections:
CANH: D2.1 (K1), IC3.7 (CANH), J2.4, J5.2, R17.1
CANL1: D2.2 (K2), IC3.6 (CANL), J2.5, J5.3, PAD2.1
CAN_CS: IC1.3 (AN1/RA1), IC2.16 (CS)
CAN_INT: IC1.23 (INT2/VMO/AN8/RB2), IC2.12 (INT), R5.1
CAN_RESET: IC1.12 (_UOE/T1OSI/CCP2/RC1), IC2.17 (RESET), R1.1
CAN_SCK: IC1.22 (INT1/SCK/SCL/AN10/RB1), IC2.13 (SCK), IC6.6 (SCK)
CAN_SDI: IC1.18 (SDO/RX/DT/RC7), IC2.14 (SI), IC6.5 (SI)
CAN_SDO: IC1.21 (INT0/FLT0/SDI/SDA/AN12/RB0), IC2.15 (SO), IC6.2 (SO)
GND: C1.1, C2.1, C3.1, C4.1, C5.1, C6.1, C7.1, C8.1, C9.1, C10.1, D2.3 (A), IC1.8 (VSS), IC1.19 (VSS), IC2.9 (GND), IC3.2 (VSS), IC3.8 (RS), IC6.4 (GND), IC7.2 (GND), J2.6, J2.7, J2.8, J4.GND, J5.4, JP4.3
MCLR: IC1.1 (_MCLR/VPP/RE3), JP4.1, R2.1
unnamed: IC1.16 (D+/VP/RC5), R7.2
unnamed: C4.2, IC2.8 (OSC1), Q1.P$1 (1)
unnamed: IC1.15 (D-/VM/RC4), R6.2
unnamed: IC1.13 (CCP1/RC2), LD1.CR
unnamed: C6.2, IC2.7 (OSC2), Q1.P$2 (2)
unnamed: LD1.A, R8.1
unnamed: IC1.17 (TX/CK/RC6), LD1.CX (CG)
unnamed: PAD1.1, R17.2
unnamed: J2.1, J2.2, J2.3, J5.1
unnamed: J4.D-, R6.1
unnamed: J4.D+, R7.1
unnamed: IC7.5 (LX), L1.1
PGC: IC1.27 (KBI2/PGC/RB6), JP4.5
PGD: IC1.28 (KBI3/PGD/RB7), JP4.4
PGM: IC1.26 (KBI1/PGM/RB5), JP4.6
RAM_CS: IC1.25 (KBI0/AN11/RB4), IC6.1 (CS)
RXD: IC2.2 (RXCAN)
SYSTEMCLOCK: IC1.10 (OSC2/CLKO/RA6), IC2.3 (CLKOUT)
TXD: IC2.1 (TXCAN), IC3.1 (TXD)
VCC: C1.2, C8.2, C10.2, IC2.18 (VCC), IC3.3 (VDD), IC7.1 (VIN), IC7.3 (/SHDN), J4.VUSB (VBUS), R1.2, R5.2
VDD: C2.2, C5.2, C7.2, C9.2, IC1.6 (RCV/T0CKI/C1OUT/RA4), IC1.20 (VDD), IC6.7 (HOLD), IC6.8 (VCC), IC7.4 (VOUT), JP4.2, L1.2, R2.2, R8.2
VREF: IC3.5 (VREF)
VUSB: C3.2, IC1.14 (VUSB)

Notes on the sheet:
Programming
Connector
CAN4VSCP USB
Status LED
Green
Not mounted by default
mount for on board
termination
R17
VCC - 5V
VDD - 3.3V
Decouplig tranceiver

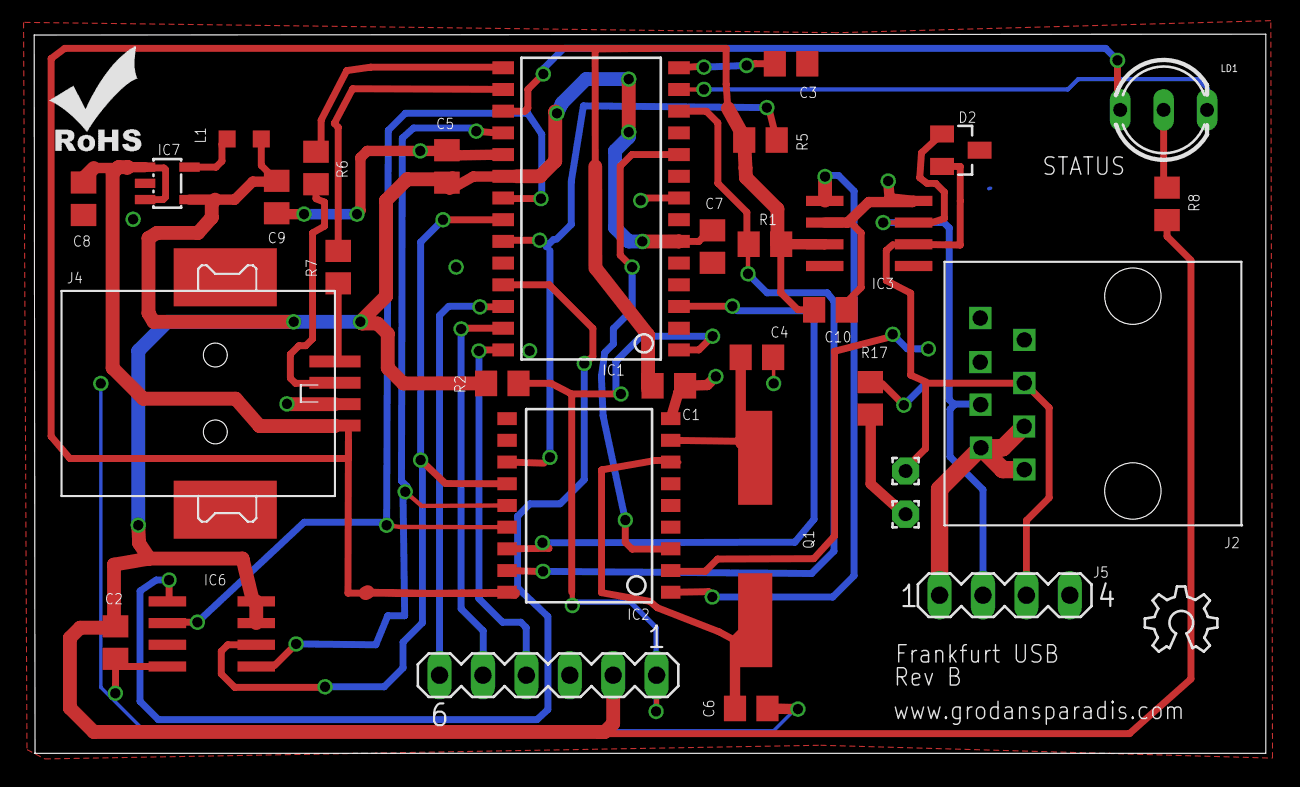
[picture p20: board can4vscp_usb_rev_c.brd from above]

Board: 2 copper layers, 72.1 x 42.1 mm, 35 parts (0 on the bottom side), 31 nets.

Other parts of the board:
U$1: OSHW_6X150_NOTEXT
U$2: ROHS_SILK
U$4: VSCP_LOGO2

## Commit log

2015-08-17 Initial checkin
    [bom.ods, can4vscp_usb_rev_A.brd, can4vscp_usb_rev_A.sch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]
2015-11-03 Added boxed version and stepped to rev c
    [bom.ods, can4vscp_usb_rev_B.brd, can4vscp_usb_rev_B.sch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]
2015-11-03 Adding gerbers for the enclosure version
2015-12-03 Corrected processor type
    [can4vscp_usb_rev_c.brd, can4vscp_usb_rev_c.sch]
2026-05-04 Added new STM32 based design
    [ADM3050EBRIZ-RL.stp, EDI2CAP.CFG, QFP50P900X900X160-48N.PcbLib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]
2026-05-04 Removed manual dirt
    [diff.txt]
2026-05-04 Changed crystal to TXC 7V series
    [mcu.kicad_sch]
2026-05-04 Fixed power issue
    [can.kicad_sch, leds.kicad_sch, mcu.kicad_sch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]
2026-05-04 Added butons
    [can.kicad_sch, leds.kicad_sch, mcu.kicad_sch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]
2026-05-08 Reversion A schema and PCB
    [2047110001.stp, can.kicad_sch, leds.kicad_sch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]
2026-05-08 Fixed 3D models
    [EDI2CAP.CFG, SOT65P280X110-8N.PcbLib, TCAN3403DDFRQ1.SchLib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]

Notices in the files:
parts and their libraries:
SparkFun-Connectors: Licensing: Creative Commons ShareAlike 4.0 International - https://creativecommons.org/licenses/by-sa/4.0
